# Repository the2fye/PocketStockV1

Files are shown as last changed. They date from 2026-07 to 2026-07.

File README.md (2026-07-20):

<div align="center">

# 📈 PocketStock

**A palm-sized, WiFi-connected stock ticker built from under $10 of parts. Live prices, sparkline charts, and a market clock — on your desk, off your phone.**

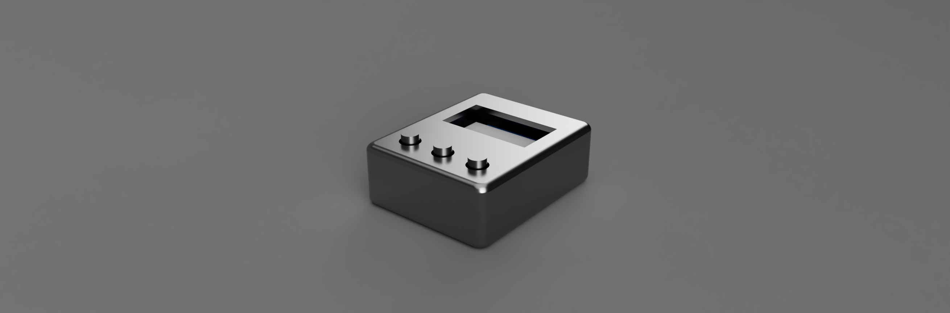
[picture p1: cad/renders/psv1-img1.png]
PocketStock render


*ESP32-C3 · SSD1306 OLED · 3 buttons · Finnhub API · $9.45 BOM · 100% open source*

</div>

---

## What it does

PocketStock is a tiny desktop gadget that pulls **live stock quotes** from the [Finnhub API](https://finnhub.io) over WiFi and displays them on a crisp 0.96" OLED. Scroll through your watchlist, open a ticker, and get:

- 💵 **Live price**, refreshed every 3 seconds
- 📉 **Change since previous close**
- 📊 **Sparkline chart** of the last 20 price updates
- 🕐 **Real-time clock** synced via NTP
- 🔔 **Market open/closed indicator** (knows NYSE hours, including the 9:30 open)

Navigation is a simple three-button menu system — up, down, select — with **long-press to go back**. No touchscreen, no app, no subscription.

Is it going to replace the military-grade supercomputer in your other pocket? No. But it's a dedicated, glanceable market display that doesn't buzz, doesn't distract, and doesn't try to sell you anything. It just tells you the number. (V1 runs off USB power — true pocket portability is on the roadmap.)

Oh, and there's **Pong** hidden in the settings menu. Because every good gadget needs a game.

## Hardware

The entire build costs **$9.45** in parts:

| Ref | Part | Qty | Cost |
|-----|---|:---:|-----:|
| U1 | ESP32-C3 SuperMini | 1 | $6.00 |
| U2 | SSD1306 OLED display, 128×64 I²C (addr `0x3C`) | 1 | $3.00 |
| SW1–SW3 | 6mm tactile push buttons | 3 | $0.45 |
| | **Total** | | **$9.45** |

Plus a custom PCB and a 3D-printed enclosure (STLs in [`cad/psv1-stls`](cad/psv1-stls)). Full parts list with supplier links: [`hardware/bill-of-materials-psv1.csv`](hardware/bill-of-materials-psv1.csv)

Everything you need to reproduce or remix the board is included: ready-to-fab gerbers in [`hardware/gerbers`](hardware/gerbers), the **full KiCad project** (schematic + board layout) in [`hardware/pcb`](hardware/pcb), and a **STEP model** of the assembled PCB for designing your own enclosure around it.

### Wiring

| Signal | ESP32-C3 pin |
|---|:---:|
| OLED SDA | GPIO 4 |
| OLED SCL | GPIO 5 |
| Button — Up | GPIO 6 |
| Button — Down | GPIO 7 |
| Button — Select | GPIO 8 |

Buttons are active-low using the ESP32's internal pull-ups — wire each button between its GPIO and GND. No external resistors needed.

### Schematic

<div align="center">
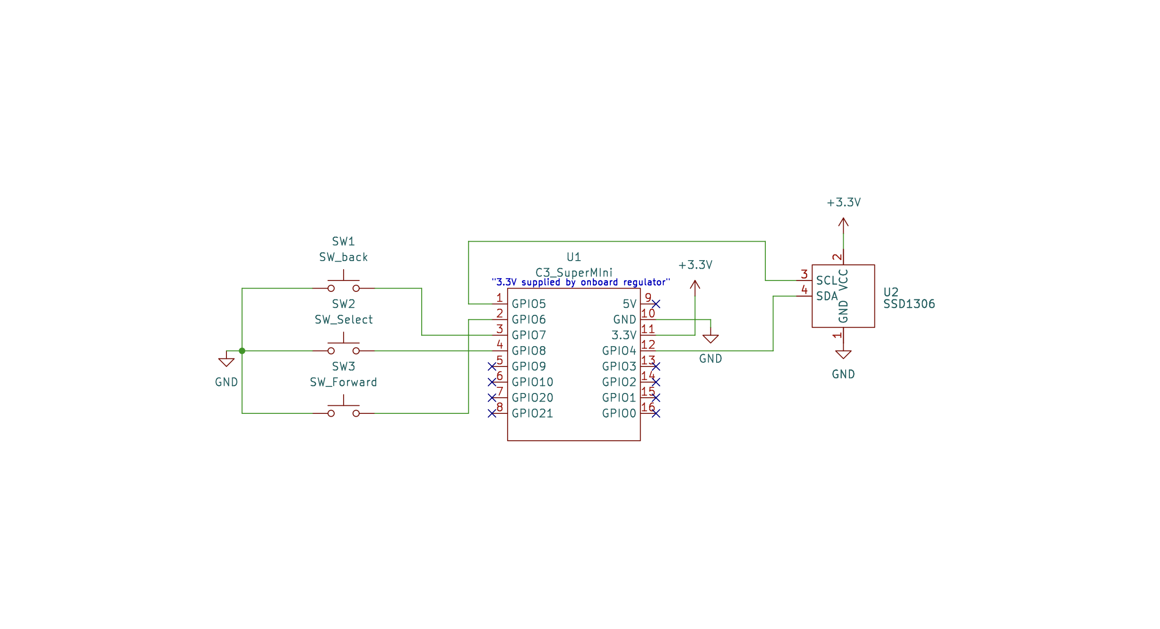
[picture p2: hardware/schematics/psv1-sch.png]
PocketStock schematic

</div>

Full vector version: [`hardware/schematics/psv1-sch.pdf`](hardware/schematics/psv1-sch.pdf) · KiCad source: [`hardware/schematics`](hardware/schematics)

## Build it

### 1. Print the enclosure

Print the three STLs in [`cad/psv1-stls`](cad/psv1-stls): `base-v3.stl`, `lid-v3.stl`, and `button-v3.stl` (×3).

### 2. Order the PCB

Upload the files in [`hardware/gerbers`](hardware/gerbers) to your favorite fab (JLCPCB, PCBWay, OSH Park). Prefer to breadboard first? The [schematic](#schematic) above is all you need — or open the full KiCad project in [`hardware/pcb`](hardware/pcb) to modify the board itself.

### 3. Flash the firmware

1. Install the [Arduino IDE](https://www.arduino.cc/en/software) and add ESP32 board support (Boards Manager → search "esp32" → install Espressif's package).
2. Install these libraries via Library Manager:
   - `Adafruit SSD1306`
   - `Adafruit GFX Library`
   - `ArduinoJson`
3. Open [`firmware/PocketStockV1/PocketStockV1.ino`](firmware/PocketStockV1/PocketStockV1.ino) and set your own values:

```cpp
const char* ssid   = "YOUR_WIFI_SSID";       // open networks supported; add a password arg to WiFi.begin() for secured ones
const char* apiKey = "YOUR_FINNHUB_API_KEY"; // free at https://finnhub.io
```

4. Edit the `stocks[]` array to build your own watchlist — any Finnhub-supported ticker works.
5. Select **ESP32C3 Dev Module** as the board, hit upload, and watch the boot logo roll.

> **Note:** Finnhub's free tier allows 60 calls/minute. PocketStock polls every 3 seconds (20/min), so you're well within limits — but get your *own* free key rather than sharing one.

## Controls

| Action | What it does |
|---|---|
| **Up / Down** | Move through menus and your stock list |
| **Select** (short press) | Open the highlighted item |
| **Select** (hold ~0.7s) | Go back |
| **Up / Down** (in Pong) | Move your paddle 🏓 |

## Gallery

<div align="center">
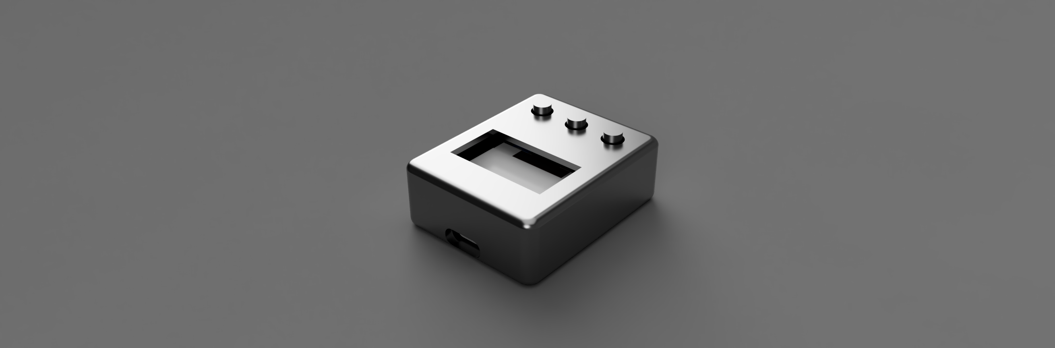
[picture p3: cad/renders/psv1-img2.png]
PocketStock render — alternate angle

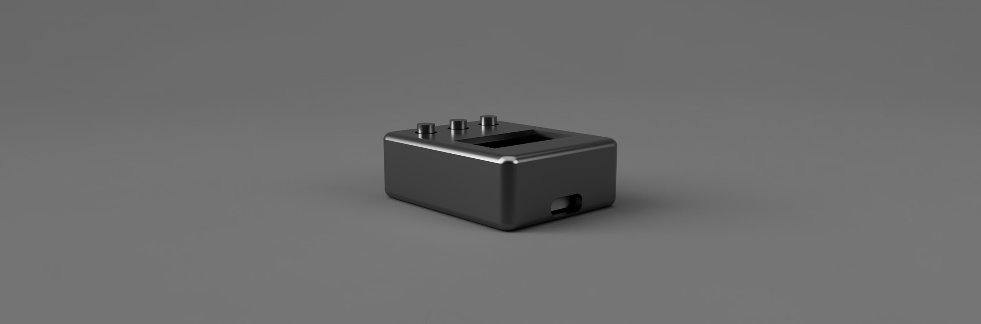
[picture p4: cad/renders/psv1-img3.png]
PocketStock render — alternate angle

</div>

## Repo map

```
├── cad/
│   ├── psv1-stls/    3D-printable enclosure (base, lid, buttons)
│   └── renders/      Enclosure renders
├── docs/             Architecture doc — how the firmware & hardware work
├── firmware/         ESP32-C3 Arduino sketch
└── hardware/
    ├── gerbers/      Ready-to-fab PCB files
    ├── pcb/          Full KiCad project + STEP model + board renders
    ├── schematics/   Schematic (PNG, PDF, KiCad source)
    └── bill-of-materials-psv1.csv
```

## Roadmap

- [ ] WiFi provisioning (no hardcoded SSID)
- [ ] Store API key + watchlist in flash, editable from the device
- [ ] Percent-change view and daily high/low
- [ ] Crypto ticker support
- [ ] Battery power + deep sleep

## License

See [LICENSE](LICENSE). Fork it, print it, mod it — and if you build one, open an issue with a photo. I'd love to see it.

---

<div align="center">
Built by <a href="https://github.com/the2fye">@the2fye</a> · Powered by white monsters and lots of dior sausage ;)
</div>

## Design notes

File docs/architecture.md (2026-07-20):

# PocketStock Architecture

This document describes how PocketStock works internally — the hardware layout, the firmware's structure, and how data flows from the Finnhub API to the pixels on the OLED.

## System overview

PocketStock is a single-microcontroller design. An ESP32-C3 SuperMini does everything: it drives the display, reads the buttons, maintains WiFi, fetches stock quotes, keeps time, and runs the UI (and Pong). There is no companion app or server — the device talks directly to two external services over WiFi:

```
[Buttons] ──► ESP32-C3 ──► [SSD1306 OLED]
                 │
                 ├──► Finnhub REST API  (stock quotes, HTTPS)
                 └──► pool.ntp.org      (time sync, NTP)
```

## Hardware

The ESP32-C3 talks to the SSD1306 OLED (128×64, address `0x3C`) over I²C, with SDA on GPIO 4 and SCL on GPIO 5. The three buttons — Up (GPIO 6), Down (GPIO 7), Select (GPIO 8) — are wired between their pins and ground, using the ESP32's internal pull-up resistors. A pressed button reads LOW; no external components are needed.

Power comes over USB. The ESP32-C3 SuperMini's onboard regulator supplies 3.3 V to the display.

## Firmware structure

The firmware (`firmware/PocketStockV1/PocketStockV1.ino`) is a single-file Arduino sketch organized around a **finite state machine**. A `UIState` enum tracks which screen is active:

```
MAIN_MENU ──► STOCK_LIST ──► STOCK_VIEW
    │
    └──► SETTINGS_MENU ──► SETTINGS_WIFI
                      ├──► SETTINGS_ABOUT
                      └──► GAME_PONG
```

Every iteration of `loop()` does three things: interpret button input in the context of the current state, run any per-state periodic work (quote fetching in `STOCK_VIEW`, physics in `GAME_PONG`), and redraw the screen when something changed. Screens are drawn by dedicated `draw*()` functions; drawing happens on demand rather than every frame, except in Pong.

### Input handling

Up and Down are simple polled reads with a 150 ms delay acting as debounce and auto-repeat rate. Select is more interesting: the firmware timestamps the press and measures duration on release. A release under 700 ms is a **short press** (enter/confirm); holding 700 ms or longer is a **long press** (back). This gives three buttons the navigational power of five — no dedicated back button needed, which keeps the PCB and enclosure simpler.

### Quote fetching

While in `STOCK_VIEW`, the firmware polls Finnhub's `/quote` endpoint for the selected ticker every 3 seconds (non-blocking — it checks `millis()` rather than sleeping). The JSON response is parsed with ArduinoJson into current price (`c`) and change since previous close (`d`). At 20 requests/minute this stays comfortably inside Finnhub's free-tier limit of 60/minute.

### Sparkline

Each fetched price is pushed into a 20-slot **ring buffer**. The sparkline renderer finds the min and max across the buffer, then maps each stored price into a 14×40 px region on the right edge of the stock view, connecting consecutive points with lines. Because scaling is relative to the buffered window, the sparkline always uses the full height of its region — it shows the *shape* of recent movement, not absolute scale. The buffer resets when you switch tickers so one stock's history never bleeds into another's.

### Time and market status

On boot, after WiFi connects, the firmware syncs with `pool.ntp.org` (configured for US Eastern, UTC−5 with DST offset). The stock view header shows the current time plus a market indicator: `isMarketOpen()` checks for weekdays between 9:30 AM and 4:00 PM and the display shows an open or closed glyph accordingly. This is a display hint only — the device still fetches quotes when markets are closed; prices simply don't move.

### Pong

Selecting Pong from settings enters a dedicated game loop: player paddle on the left (Up/Down buttons), a simple AI paddle on the right that tracks the ball's vertical position, score incremented per successful return, high score kept for the session. The game runs at roughly 80 fps (12 ms frame delay) and exits via the same long-press-back gesture as everything else.

## Boot sequence

1. Configure button GPIOs and I²C, initialize the display.
2. Show the boot logo (2 s).
3. Connect to WiFi (blocking, with an on-screen message).
4. Sync time via NTP.
5. Enter `MAIN_MENU`.

## Design constraints and tradeoffs

**Single-core simplicity.** Everything runs in one loop with no RTOS tasks. The tradeoff: the HTTPS fetch briefly blocks input, so button presses during the ~200–500 ms of a quote request are dropped. Acceptable for this UI; a future version could move fetching to a FreeRTOS task.

**No persistence.** WiFi credentials, the API key, and the watchlist are compile-time constants; the Pong high score lives in RAM. Storing these in NVS flash (editable from the device) is the top item on the roadmap.

**Polling over streaming.** Finnhub offers a websocket for real-time trades, but REST polling every 3 s is dramatically simpler, easier on RAM, and indistinguishable on a 128×64 display.

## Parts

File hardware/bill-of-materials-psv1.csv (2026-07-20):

Reference | Part Name | Value | Quantity | Manufacturer | Part Number | Unit Cost | Total Cost | Link
U1 | ESP32-C3 SuperMini |  | 1 | Generic | ESP32-C3-SuperMini | 6 | 6 | https://lonelybinary.com/en-us/products/c3s
U2 | OLED Display | SSD1306 0.96" | 1 | Generic | SSD1306 | 3 | 3 | https://shorturl.at/MK3HG
SW1 | Push Button | 6mm Tactile | 1 | Generic | SW_PUSH_6mm | 0.15 | 0.15 | https://www.robotpark.com/IC-200-4-Pin-6x6x1mm-Tactile-Push-Button-Switch
SW2 | Push Button | 6mm Tactile | 1 | Generic | SW_PUSH_6mm | 0.15 | 0.15 | https://www.robotpark.com/IC-200-4-Pin-6x6x1mm-Tactile-Push-Button-Switch
SW3 | Push Button | 6mm Tactile | 1 | Generic | SW_PUSH_6mm | 0.15 | 0.15 | https://www.robotpark.com/IC-200-4-Pin-6x6x1mm-Tactile-Push-Button-Switch
TOTAL |  |  |  |  |  |  | 9.45

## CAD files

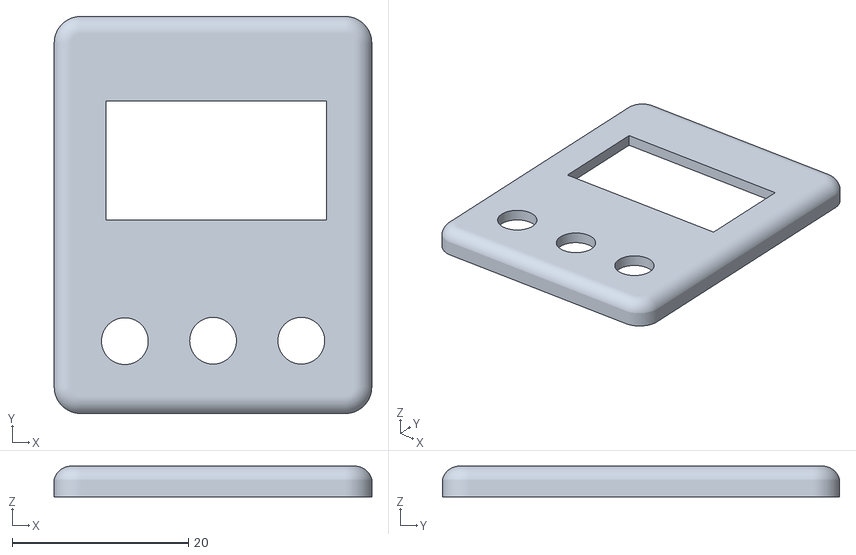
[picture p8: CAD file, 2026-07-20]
cad/psv1-stls/lid-v3.stl
36.0 x 45.0 x 3.50

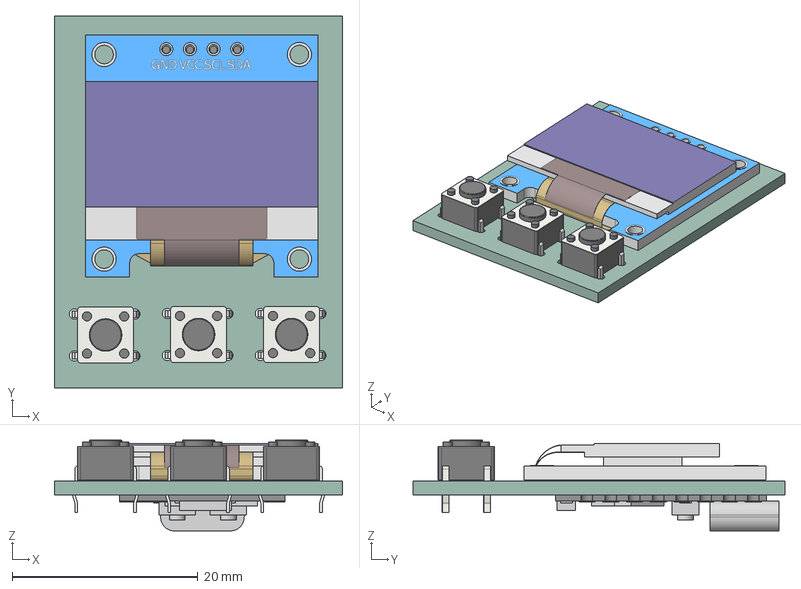
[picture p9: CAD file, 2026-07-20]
hardware/pcb/PocketStockV2.step
31.0 x 40.0 x 9.78 mm
ssd1306 step
SW_PUSH_6mm x 3
PocketStockV2_PCB

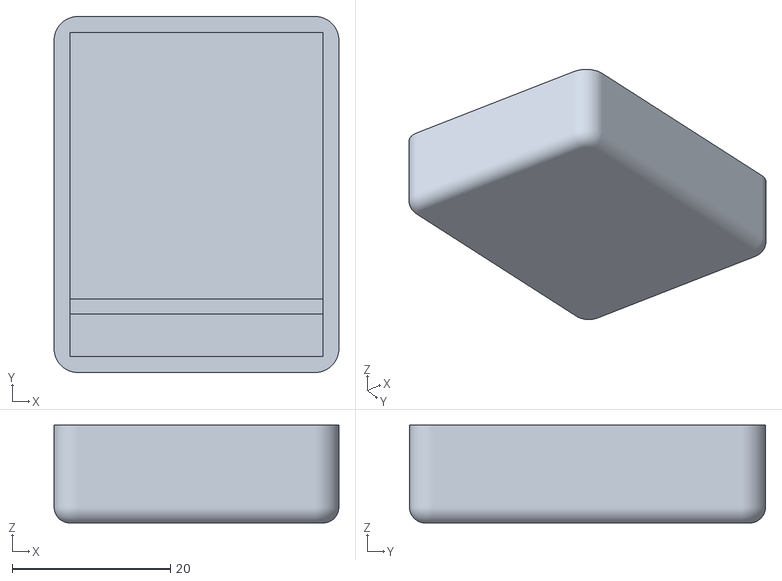
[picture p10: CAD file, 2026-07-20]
cad/psv1-stls/base-v3.stl
36.0 x 45.0 x 12.4

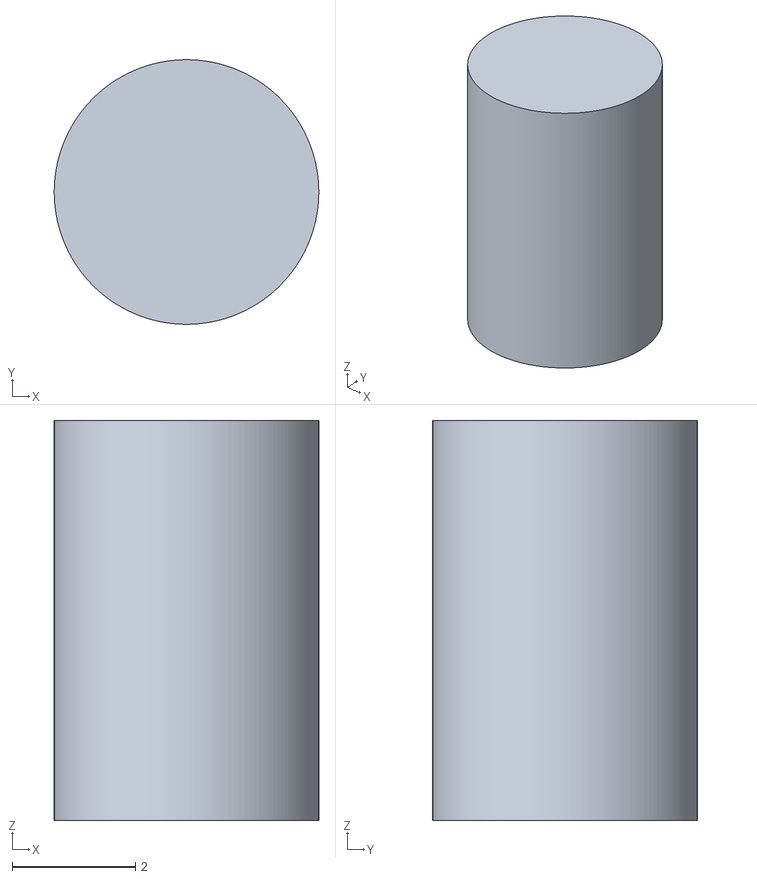
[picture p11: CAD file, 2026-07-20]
cad/psv1-stls/button-v3.stl
4.30 x 4.30 x 6.50

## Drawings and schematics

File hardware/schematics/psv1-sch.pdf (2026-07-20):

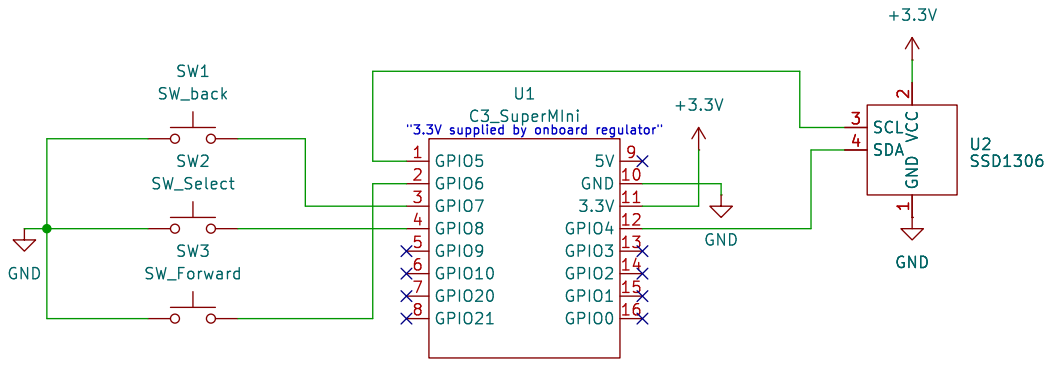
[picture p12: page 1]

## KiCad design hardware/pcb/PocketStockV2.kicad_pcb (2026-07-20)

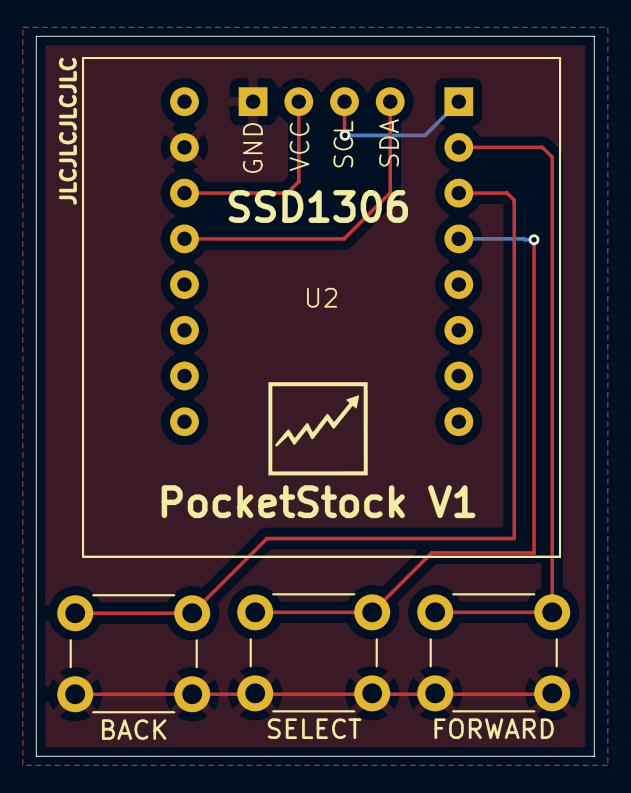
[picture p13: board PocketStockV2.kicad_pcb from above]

Board: 4 copper layers, 31.0 x 40.0 mm, 5 parts (1 on the bottom side), 7 nets.

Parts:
BACK: SW_back; SW_PUSH_6mm
FORWARD: SW_Forward; SW_PUSH_6mm
SELECT: SW_Select; SW_PUSH_6mm
U1: C3_SuperMIni; ESP_32_C3_SuperMini
U2: SSD1306

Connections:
+3.3V: U1.11 (3.3V), U2.2 (VCC)
GND: BACK.1, FORWARD.1, SELECT.1, U1.10 (GND), U2.1 (GND)
unnamed: U1.12 (GPIO4), U2.4 (SDA)
unnamed: U1.1 (GPIO5), U2.3 (SCL)
unnamed: FORWARD.2, U1.2 (GPIO6)
unnamed: BACK.2, U1.3 (GPIO7)
unnamed: SELECT.2, U1.4 (GPIO8)

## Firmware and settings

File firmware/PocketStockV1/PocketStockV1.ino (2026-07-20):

#include <WiFi.h>
#include <HTTPClient.h>
#include <ArduinoJson.h>
#include <Wire.h>
#include <Adafruit_GFX.h>
#include <Adafruit_SSD1306.h>
#include <time.h>

/* ================= DISPLAY ================= */
#define SCREEN_WIDTH 128
#define SCREEN_HEIGHT 64
#define OLED_RESET -1
#define OLED_ADDR 0x3C
#define SDA_PIN 4
#define SCL_PIN 5
Adafruit_SSD1306 display(SCREEN_WIDTH, SCREEN_HEIGHT, &Wire, OLED_RESET);

/* ================= BUTTONS ================= */
#define BTN_UP     6
#define BTN_DOWN   7
#define BTN_SELECT 8

/* ================= WIFI ================= */
const char* ssid = "YOUR_WIFI_SSID";

/* ================= STOCKS ================= */
String stocks[] = {
  "AAPL","MSFT","NVDA","AMD","GOOGL","META","TSLA",
  "XOM","CVX","BP","SHEL","COP"
};
const int NUM_STOCKS = sizeof(stocks) / sizeof(stocks[0]);
int stockIndex = 0;
int stockScrollOffset = 0;
const int VISIBLE_STOCKS = 6;

/* ================= FINNHUB ================= */
const char* apiKey = "YOUR_FINNHUB_API_KEY";

/* ================= UI STATES ================= */
enum UIState {
  MAIN_MENU,
  STOCK_LIST,
  STOCK_VIEW,
  SETTINGS_MENU,
  SETTINGS_WIFI,
  SETTINGS_ABOUT,
  GAME_PONG
};
UIState uiState = MAIN_MENU;

/* ================= MENUS ================= */
int mainMenuIndex = 0;
int settingsIndex = 0;

/* ================= TIMING ================= */
unsigned long lastFetch = 0;
const unsigned long fetchInterval = 3000;

/* ================= LONG PRESS ================= */
bool selectHeld = false;
unsigned long selectPressTime = 0;
const unsigned long LONG_PRESS_MS = 700;

/* ================= SPARKLINE ================= */
#define GRAPH_X 112
#define GRAPH_Y 12
#define GRAPH_W 14
#define GRAPH_H 40
#define HISTORY_SIZE 20
float priceHistory[HISTORY_SIZE];
int historyIndex = 0;
bool historyFilled = false;

/* ================= TIME ================= */
const char* ntpServer = "pool.ntp.org";
const long gmtOffset_sec = -5 * 3600;
const int daylightOffset_sec = 3600;

/* ================= PONG ================= */
int paddleY = 24;
int enemyPaddleY = 24;
int ballX, ballY;
int ballVX, ballVY;
int pongScore = 0;
int pongHighScore = 0;
const int BALL_SPEED_X = 2;
const int BALL_SPEED_Y = 2;

/* ================= BOOT LOGO ================= */
void showBootScreen() {
  display.clearDisplay();
  display.setTextColor(SSD1306_WHITE);

  display.drawRect(8, 18, 28, 28, SSD1306_WHITE);
  display.drawLine(12, 40, 18, 34, SSD1306_WHITE);
  display.drawLine(18, 34, 24, 36, SSD1306_WHITE);
  display.drawLine(24, 36, 30, 26, SSD1306_WHITE);
  display.fillTriangle(28, 26, 30, 22, 32, 26, SSD1306_WHITE);

  display.setTextSize(2);
  display.setCursor(42, 20); display.println("Pocket");
  display.setCursor(42, 38); display.println("Stock");

  display.setTextSize(1);
  display.setCursor(34, 56); display.println("Market Pulse");
  display.display();
  delay(2000);
}

/* ================= HELPERS ================= */

bool isMarketOpen(struct tm* t) {
  int w = t->tm_wday, h = t->tm_hour, m = t->tm_min;
  if (w == 0 || w == 6) return false;
  if (h < 9 || h > 16) return false;
  if (h == 9 && m < 30) return false;
  if (h == 16 && m > 0) return false;
  return true;
}

void drawTimeAndMarket() {
  struct tm t;
  if (!getLocalTime(&t)) return;

  char buf[6];
  strftime(buf, sizeof(buf), "%H:%M", &t);
  display.setCursor(88, 0);
  display.print(buf);

  int x = 108, y = 10;
  if (isMarketOpen(&t)) {
    display.drawRect(x, y, 10, 10, SSD1306_WHITE);
    display.fillTriangle(x+5,y+2,x+8,y+6,x+2,y+6,SSD1306_WHITE);
  } else {
    display.fillCircle(x+5,y+5,4,SSD1306_WHITE);
    display.fillCircle(x+7,y+5,4,SSD1306_BLACK);
  }
}

/* ================= SPARKLINE ================= */

void resetHistory() {
  historyIndex = 0;
  historyFilled = false;
}

void addPrice(float p) {
  priceHistory[historyIndex++] = p;
  if (historyIndex >= HISTORY_SIZE) {
    historyIndex = 0;
    historyFilled = true;
  }
}

void drawSparkline() {
  int count = historyFilled ? HISTORY_SIZE : historyIndex;
  if (count < 2) return;

  float minP = priceHistory[0], maxP = priceHistory[0];
  for (int i = 1; i < count; i++) {
    minP = min(minP, priceHistory[i]);
    maxP = max(maxP, priceHistory[i]);
  }
  if (minP == maxP) maxP += 1;

  for (int i = 1; i < count; i++) {
    int x0 = GRAPH_X + (i-1)*GRAPH_W/(count-1);
    int x1 = GRAPH_X + i*GRAPH_W/(count-1);
    int y0 = map(priceHistory[i-1], minP, maxP, GRAPH_Y+GRAPH_H, GRAPH_Y);
    int y1 = map(priceHistory[i],   minP, maxP, GRAPH_Y+GRAPH_H, GRAPH_Y);
    display.drawLine(x0,y0,x1,y1,SSD1306_WHITE);
  }
}

/* ================= PONG ================= */

void resetPong() {
  pongHighScore = max(pongHighScore, pongScore);
  pongScore = 0;
  paddleY = 24;
  enemyPaddleY = 24;
  ballX = SCREEN_WIDTH/2;
  ballY = SCREEN_HEIGHT/2;
  ballVX = BALL_SPEED_X;
  ballVY = BALL_SPEED_Y;
}

void updatePong() {
  ballX += ballVX;
  ballY += ballVY;

  if (ballY <= 1 || ballY >= SCREEN_HEIGHT-2) ballVY *= -1;

  if (ballX <= 6 && ballY >= paddleY && ballY <= paddleY+16) {
    ballVX = BALL_SPEED_X;
    pongScore++;
  }

  if (ballX >= SCREEN_WIDTH-8 && ballY >= enemyPaddleY && ballY <= enemyPaddleY+16)
    ballVX = -BALL_SPEED_X;

  enemyPaddleY += (ballY > enemyPaddleY+8) ? 1 : -1;
  enemyPaddleY = constrain(enemyPaddleY,0,SCREEN_HEIGHT-16);

  if (ballX < 0) resetPong();
  if (ballX > SCREEN_WIDTH) {
    ballX = SCREEN_WIDTH/2;
    ballY = SCREEN_HEIGHT/2;
  }
}

void drawPong() {
  display.clearDisplay();
  display.drawRect(0,0,SCREEN_WIDTH,SCREEN_HEIGHT,SSD1306_WHITE);
  display.setCursor(18,2);
  display.print("Score:");
  display.print(pongScore);
  display.print(" Hi:");
  display.print(pongHighScore);
  display.fillRect(2,paddleY,3,16,SSD1306_WHITE);
  display.fillRect(SCREEN_WIDTH-5,enemyPaddleY,3,16,SSD1306_WHITE);
  display.fillCircle(ballX,ballY,2,SSD1306_WHITE);
  display.display();
}

/* ================= UI DRAW ================= */

void drawMainMenu() {
  display.clearDisplay();
  display.setTextSize(2);
  display.setCursor(0,12);
  display.print(mainMenuIndex==0?"> ":"  "); display.println("Stocks");
  display.setCursor(0,36);
  display.print(mainMenuIndex==1?"> ":"  "); display.println("Settings");
  display.display();
}

void drawStockList() {
  display.clearDisplay();
  display.setTextSize(1);
  for (int i=0;i<VISIBLE_STOCKS;i++) {
    int idx = stockScrollOffset+i;
    if (idx>=NUM_STOCKS) break;
    display.setCursor(0,i*10);
    display.print(idx==stockIndex?"> ":"  ");
    display.println(stocks[idx]);
  }
  display.display();
}

void drawSettingsMenu() {
  const char* items[]={"WiFi Info","About","Pong","Back"};
  display.clearDisplay();
  display.setTextSize(1);
  for(int i=0;i<4;i++){
    display.setCursor(0,i*10);
    display.print(settingsIndex==i?"> ":"  ");
    display.println(items[i]);
  }
  display.display();
}

void drawWiFiInfo() {
  display.clearDisplay();
  display.setTextSize(1);
  display.setCursor(0,0); display.println("WiFi Info");
  display.drawLine(0,9,127,9,SSD1306_WHITE);
  display.setCursor(0,14); display.print("SSID: "); display.println(WiFi.SSID());
  display.setCursor(0,24); display.print("RSSI: "); display.print(WiFi.RSSI()); display.println(" dBm");
  display.setCursor(0,34); display.println("IP:");
  display.setCursor(0,44); display.println(WiFi.localIP());
  display.display();
}

void drawAbout() {
  display.clearDisplay();
  display.setTextSize(1);
  display.setCursor(0,0); display.println("About");
  display.drawLine(0,9,127,9,SSD1306_WHITE);
  display.setCursor(0,14); display.println("PocketStock");
  display.setCursor(0,24); display.println("ESP32-C3");
  display.setCursor(0,34); display.println("Finnhub API");
  display.setCursor(0,44); display.println("v1.0");
  display.display();
}

/* ================= STOCK VIEW ================= */

void fetchAndDrawStockView() {
  HTTPClient http;
  String url="https://finnhub.io/api/v1/quote?symbol="+stocks[stockIndex]+"&token="+apiKey;
  http.begin(url);
  if(http.GET()==200){
    StaticJsonDocument<256> doc;
    deserializeJson(doc,http.getString());
    addPrice(doc["c"]);
    display.clearDisplay();
    display.setCursor(0,0); display.print(stocks[stockIndex]);
    drawTimeAndMarket();
    display.setTextSize(2);
    display.setCursor(0,18); display.print("$"); display.print((float)doc["c"],2);
    display.setTextSize(1);
    display.setCursor(0,52); display.print("Chg "); display.print((float)doc["d"],2);
    drawSparkline();
    display.display();
  }
  http.end();
}

/* ================= SETUP ================= */

void setup() {
  pinMode(BTN_UP,INPUT_PULLUP);
  pinMode(BTN_DOWN,INPUT_PULLUP);
  pinMode(BTN_SELECT,INPUT_PULLUP);

  Wire.begin(SDA_PIN,SCL_PIN);
  display.begin(SSD1306_SWITCHCAPVCC,OLED_ADDR);
  display.setTextColor(SSD1306_WHITE);

  showBootScreen();

  display.clearDisplay();
  display.setCursor(0,28);
  display.println("Connecting WiFi...");
  display.display();

  WiFi.begin(ssid);
  while(WiFi.status()!=WL_CONNECTED) delay(100);

  configTime(gmtOffset_sec,daylightOffset_sec,ntpServer);
  drawMainMenu();
}

/* ================= LOOP ================= */

void loop() {

  /* ----- LONG PRESS BACK ----- */
  bool sel = digitalRead(BTN_SELECT)==LOW;
  if (sel && !selectHeld) {
    selectHeld=true;
    selectPressTime=millis();
  }
  if (!sel && selectHeld) {
    selectHeld=false;
    if (millis()-selectPressTime>=LONG_PRESS_MS) {
      if (uiState==STOCK_VIEW) { uiState=STOCK_LIST; drawStockList(); }
      else if (uiState==STOCK_LIST) { uiState=MAIN_MENU; drawMainMenu(); }
      else if (uiState==SETTINGS_WIFI || uiState==SETTINGS_ABOUT || uiState==GAME_PONG) {
        uiState=SETTINGS_MENU; drawSettingsMenu();
      }
      return;
    }
  }

  /* ----- STOCK VIEW UPDATE ----- */
  if (uiState==STOCK_VIEW && millis()-lastFetch>fetchInterval) {
    lastFetch=millis();
    fetchAndDrawStockView();
  }

  /* ----- PONG ----- */
  if (uiState==GAME_PONG) {
    if (!digitalRead(BTN_UP)) paddleY-=2;
    if (!digitalRead(BTN_DOWN)) paddleY+=2;
    paddleY=constrain(paddleY,0,SCREEN_HEIGHT-16);
    updatePong();
    drawPong();
    delay(12);
    return;
  }

  /* ----- UP ----- */
  if (!digitalRead(BTN_UP)) {
    if (uiState==MAIN_MENU && mainMenuIndex>0) { mainMenuIndex--; drawMainMenu(); }
    else if (uiState==STOCK_LIST && stockIndex>0) {
      stockIndex--;
      if (stockIndex<stockScrollOffset) stockScrollOffset--;
      drawStockList();
    }
    else if (uiState==SETTINGS_MENU && settingsIndex>0) { settingsIndex--; drawSettingsMenu(); }
    delay(150);
  }

  /* ----- DOWN ----- */
  if (!digitalRead(BTN_DOWN)) {
    if (uiState==MAIN_MENU && mainMenuIndex<1) { mainMenuIndex++; drawMainMenu(); }
    else if (uiState==STOCK_LIST && stockIndex<NUM_STOCKS-1) {
      stockIndex++;
      if (stockIndex>=stockScrollOffset+VISIBLE_STOCKS) stockScrollOffset++;
      drawStockList();
    }
    else if (uiState==SETTINGS_MENU && settingsIndex<3) { settingsIndex++; drawSettingsMenu(); }
    delay(150);
  }

  /* ----- SHORT PRESS SELECT ----- */
  if (!sel && millis()-selectPressTime<LONG_PRESS_MS && selectPressTime!=0) {
    selectPressTime=0;

    if (uiState==MAIN_MENU) {
      if (mainMenuIndex==0) { uiState=STOCK_LIST; stockScrollOffset=0; drawStockList(); }
      else { uiState=SETTINGS_MENU; settingsIndex=0; drawSettingsMenu(); }
    }
    else if (uiState==STOCK_LIST) {
      uiState=STOCK_VIEW;
      resetHistory();
      lastFetch=0;
    }
    else if (uiState==SETTINGS_MENU) {
      if (settingsIndex==0) { uiState=SETTINGS_WIFI; drawWiFiInfo(); }
      else if (settingsIndex==1) { uiState=SETTINGS_ABOUT; drawAbout(); }
      else if (settingsIndex==2) { uiState=GAME_PONG; resetPong(); }
      else { uiState=MAIN_MENU; drawMainMenu(); }
    }
  }
}

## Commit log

2026-07-20 added STL files for psv1
    [base V3.stl, buttton V3.stl, lid v3.stl]
2026-07-20 STL files added
    [base V3.stl, buttton V3.stl, lid v3.stl]
2026-07-20 fixed directory discrepancies
    [base V3.stl, buttton V3.stl, lid v3.stl]
2026-07-20 Clean up repo: remove .DS_Store, fix naming to V1, replace spaces and apostrophes with dashes
    [base-v3.stl, bill-of-materials-psv1.csv, button-v3.stl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]
2026-07-20 Add full README with BOM, gallery, and build guide; rename renders to dash format
2026-07-20 Replace corrupted schematic PDF, fix V2 naming in schematics folder
    [PocketStockV1.kicad_sch]
2026-07-20 Re-add schematic PDF as psv1-sch.pdf
2026-07-20 Replace schematic PDF with clean re-export
2026-07-20 Replace schematic PDF with KiCad plot
2026-07-20 Add full KiCad project and STEP model
    [PocketStockV2.kicad_pcb, PocketStockV2.kicad_sch, PocketStockV2.step]
2026-07-20 Remove KiCad footprint cache from version control
2026-07-20 Add schematic PNG for inline viewing
2026-07-20 Replace hardcoded credentials with placeholders
    [PocketStockV1.ino]
2026-07-20 Repo cleanup: remove empty files, dedupe gitignore, rename PCB renders
2026-07-20 Write architecture doc covering hardware, firmware state machine, and data flow
2026-07-20 Fix repo map, add schematic section, document KiCad sources
2026-07-20 Fix display size in BOM (0.96in, 128x64)
    [bill-of-materials-psv1.csv]
